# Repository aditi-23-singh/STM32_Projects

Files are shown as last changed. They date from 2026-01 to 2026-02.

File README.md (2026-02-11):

## Distributed Dual-Node Stepper Motor Control System
Bi-Directional UART Communication | Dual STM32 | TMC2208 | Event-Driven Firmware

## Project Summary

Designed and implemented a distributed embedded control architecture using two STM32F051 microcontrollers communicating over bi-directional UART, where both nodes are capable of controlling the same stepper motor through a TMC2208 driver.

The system supports:

    Motor control from either board
    Real-time command arbitration
    Single click → Start/Stop
    Double click → Reverse direction
    Long press → Mode control
    Deterministic timer-based pulse generation
    LED-assisted hardware debugging

This project demonstrates distributed embedded design, peripheral-level control, communication protocol handling, and real-time event synchronization.

## System Architecture
Both STM32 boards:
    
    Scan user inputs
    Generate control commands
    Transmit and receive via UART
    Update motor state based on synchronized command logic

Motor control authority is dynamically managed through command synchronization.

## Core Engineering Components
1. Bi-Directional UART Communication
    
    Full-duplex UART configuration
    Interrupt-driven RX handling
    Lightweight command protocol
    Conflict handling logic
    Command acknowledgment strategy

Key focus areas:

    Clock accuracy & baud rate matching
    Framing reliability
    Data integrity verification
    Real-time synchronization

This demonstrates understanding of multi-node embedded systems and communication integrity.

2️. Event-Based Input Engine

Implemented a structured FSM to detect:

    Single click
    Double click (timing window based)
    Long press
    Double click triggers direction reversal.

Key techniques:
    
    Edge detection
    Non-blocking timing logic
    Debounce filtering
    Deterministic state transitions

This reflects correct event-driven firmware design rather than delay-based logic.

3️. Deterministic Motor Control (TMC2208 – STEP/DIR Mode)

    Hardware timer-based pulse generation
    Adjustable step frequency
    Direction toggling without step loss
    Safe enable/disable sequencing
    Synchronization with UART events

Ensured:
    
    No missed steps during direction changes
    No blocking delays
    Pulse width constraints respected
    Stable motor operation under distributed command input

4️. Distributed Control Handling
    
    Since both boards can issue motor commands:
    Implemented command synchronization logic
    Prevented inconsistent motor states
    Ensured deterministic behavior under concurrent inputs

This models real-world distributed embedded systems where multiple controllers share authority.

5️. Structured Hardware Debugging

Used LED signaling as a deterministic debug interface:

    UART transmit/receive confirmation
    State machine transitions
    Direction change verification
    Error detection states

Also performed:

    Register-level inspection
    Timer debugging
    Peripheral clock validation
    Step signal probing

Demonstrates disciplined debugging methodology.

## Engineering Challenges Solved

    Reliable double-click detection under timing constraints
    UART synchronization between two MCUs
    Preventing step loss during direction reversal
    Avoiding race conditions in distributed control
    Maintaining deterministic pulse generation

## What This Project Demonstrates

This project reflects:

    Multi-controller embedded system design
    Real-time event-driven firmware
    Deterministic motor control
    Communication protocol implementation
    Structured debugging methodology
    Hardware-level reasoning under timing constraints
    It models a scaled-down version of distributed hardware control systems used in industrial and silicon enablement environments.
    Maintaining deterministic pulse generation

## Potential Extensions
    
    DMA-based UART communication
    Acceleration ramp (trapezoidal velocity profile)
    Arbitration protocol with priority logic
    RTOS-based task scheduling
    Closed-loop feedback with encoder
    CRC-based command validation

### Author

Aditi Singh
B.Tech – Electronics & Communication Engineering
NIT Sikkim

Focus Areas:

    Embedded Systems
    VLSI & Chip Design
    Hardware-Software Co-Design
    System Architecture

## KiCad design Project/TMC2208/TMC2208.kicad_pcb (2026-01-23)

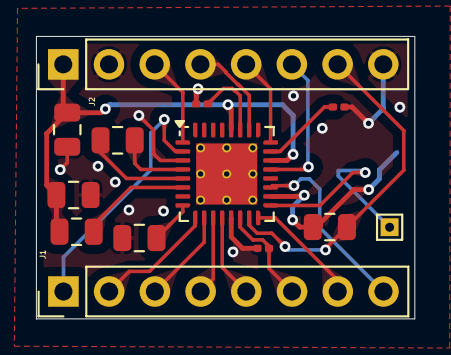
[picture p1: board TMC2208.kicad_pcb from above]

Board: 2 copper layers, 21.0 x 15.7 mm, 14 parts (1 on the bottom side), 22 nets.

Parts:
C1, C3, C6: 100nF; C_0805_2012Metric
C2: 22nF; C_0805_2012Metric
C4: 130uF; C_0805_2012Metric
C5: 4.7uF; C_0805_2012Metric
J1, J2: Conn_01x08_Pin; PinHeader_1x08_P2.54mm_Vertical
R1, R2: 0.11E; R_0201_0603Metric
R5: 10K; R_0201_0603Metric
R6: R_Variable; Potentiometer_Bourns_TC33X_Vertical
U2: TMC2208-LA; TQFN-32-1EP_5x5mm_P0.5mm_EP3.4x3.4mm_ThermalVias
Vref1: TestPoint_THTPad_1.0x1.0mm_Drill0.5mm

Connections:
/DIAG: J1.4, U2.11 (DIAG)
/DIR: J1.8, U2.19 (DIR)
/EN: J1.1, U2.2 (ENN)
/INDEX: J1.5, U2.12 (INDEX)
/M1A: J2.5, U2.24 (OA1)
/M1B: J2.4, U2.26 (OB1)
/M2A: J2.6, U2.21 (OA2)
/M2B: J2.3, U2.1 (OB2)
/MS1: J1.2, U2.9 (MS1)
/MS2: J1.3, U2.10 (MS2)
/PDN_UART: J1.6, R5.2, U2.14 (PDN_UART)
/STEP: J1.7, U2.16 (STEP)
/VIO: C3.2, J2.7, U2.15 (VCC_IO)
/VM: C1.1, C4.1, C6.1, J2.1, U2.22 (VS), U2.28 (VS)
GND: C3.1, C4.2, C5.2, C6.2, J2.2, J2.8, R1.2, R2.2, R5.1, R6.1, U2.3 (GND), U2.13 (CLK), U2.18 (GND)
unnamed: C5.1, U2.8 (5VOUT)
unnamed: R2.1, U2.23 (BRA)
unnamed: R1.1, U2.27 (BRB)
unnamed: C2.1, U2.5 (CPI)
unnamed: C2.2, U2.4 (CPO)
unnamed: C1.2, U2.6 (VCP)
unnamed: R6.2, U2.17 (VREF), Vref1.1

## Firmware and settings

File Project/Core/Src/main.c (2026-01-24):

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
/* Includes ------------------------------------------------------------------*/
#include "main.h"
#include "usart.h"
#include "gpio.h"

/* USER CODE BEGIN Includes */
#include "Application.h"
#include "UART_Application.h"
#include "ButtonCore.h"
#include "LED_Controller.h"
#include <stdio.h>
#include "TMC2208_Registers.h"
#include "TMC2208_Driver.h"

/* USER CODE END Includes */


/* USER CODE BEGIN PV */
Button_t userButton;

TMC2208_t motor1;

/* USER CODE END PV */

void SystemClock_Config(void);
/**
  * @brief  The application entry point.
  * @retval int
  */
int main(void)
{

  /* MCU Configuration--------------------------------------------------------*/

  /* Reset of all peripherals, Initializes the Flash interface and the Systick. */
  HAL_Init();

  /* Configure the system clock */
  SystemClock_Config();

  /* USER CODE BEGIN SysInit */
  MX_USART1_UART_Init();
  MX_USART2_UART_Init();
  ApplicationInit();
  ButtonCore_Init(&userButton, Button_GPIO_Port, Button_Pin);


  /* USER CODE END SysInit */

  /* Initialize all configured peripherals */
  MX_GPIO_Init();
  MX_USART1_UART_Init();
  MX_USART2_UART_Init();
  /* Infinite loop */
  /* USER CODE BEGIN WHILE */


 while (1)
 {

//
	  ApplicationProcess();
	  ButtonCore_Update(&userButton);
	  LCDApplication_Process();

    /* USER CODE END WHILE */

    /* USER CODE BEGIN 3 */


  }
  /* USER CODE END 3 */
}

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
/* USER CODE BEGIN 4 */

void HAL_SYSTICK_Callback(void)
{

    HandleTick();
}

void HAL_UART_RxCpltCallback(UART_HandleTypeDef *huart)
{


    if(huart->Instance == USART1)
    {
        UART_OnByteReceived();
    }

}
/* USER CODE END 4 */
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


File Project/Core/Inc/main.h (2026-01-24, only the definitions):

#define ROW1_Pin GPIO_PIN_0
#define ROW1_GPIO_Port GPIOC
#define ROW2_Pin GPIO_PIN_1
#define ROW2_GPIO_Port GPIOC
#define ROW3_Pin GPIO_PIN_2
#define ROW3_GPIO_Port GPIOC
#define ROW4_Pin GPIO_PIN_3
#define ROW4_GPIO_Port GPIOC
#define Button_Pin GPIO_PIN_0
#define Button_GPIO_Port GPIOA
#define COL1_Pin GPIO_PIN_4
#define COL1_GPIO_Port GPIOC
#define COL2_Pin GPIO_PIN_5
#define COL2_GPIO_Port GPIOC
#define RS_Pin GPIO_PIN_0
#define RS_GPIO_Port GPIOB
#define E_Pin GPIO_PIN_1
#define E_GPIO_Port GPIOB
#define D4_Pin GPIO_PIN_2
#define D4_GPIO_Port GPIOB
#define COL3_Pin GPIO_PIN_6
#define COL3_GPIO_Port GPIOC
#define COL4_Pin GPIO_PIN_7
#define COL4_GPIO_Port GPIOC
#define LD4_Pin GPIO_PIN_8
#define LD4_GPIO_Port GPIOC
#define LD3_Pin GPIO_PIN_9
#define LD3_GPIO_Port GPIOC
#define SWDIO_Pin GPIO_PIN_13
#define SWDIO_GPIO_Port GPIOA
#define SWCLK_Pin GPIO_PIN_14
#define SWCLK_GPIO_Port GPIOA
#define ROW5_Pin GPIO_PIN_10
#define ROW5_GPIO_Port GPIOC
#define D5_Pin GPIO_PIN_3
#define D5_GPIO_Port GPIOB
#define D6_Pin GPIO_PIN_4
#define D6_GPIO_Port GPIOB
#define D7_Pin GPIO_PIN_5
#define D7_GPIO_Port GPIOB
#define STEP_Pin GPIO_PIN_6
#define STEP_GPIO_Port GPIOB
#define DIR_Pin GPIO_PIN_7
#define DIR_GPIO_Port GPIOB
#define EN_Pin GPIO_PIN_8
#define EN_GPIO_Port GPIOB

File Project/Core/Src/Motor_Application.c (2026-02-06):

#include "Motor_Application.h"
#include "Motor_Controller.h"
#include "gpio.h"
#include <stdio.h>
#include "string.h"

extern MotorController_t MotorControl;

#define STEPS_PER_MOVE 200
#define PERIOD_MEDIUM_US 2000
#define PERIOD_SLOW_US 5000
#define PERIOD_FAST_US 1000

void MotorApplication_Init(void) {

	Motor_Init();
}

void MotorApplication_SetMotorMode(EVENT_CODES_ENUM event) {
    switch (event) {
        case EVT_SINGLE_CLICK:
        	MotorControl.direction = -1;
        	MotorControl.period_us = PERIOD_MEDIUM_US;
        	MotorControl.steps_remaining = STEPS_PER_MOVE;
        	MotorControl.running = 1;
            break;

        case EVT_DOUBLE_CLICK:
        	MotorControl.direction = 1;
        	MotorControl.period_us = PERIOD_SLOW_US;
        	MotorControl.steps_remaining = STEPS_PER_MOVE;
        	MotorControl.running = 1;
            break;

        case EVT_HOLD_START:
        	MotorControl.direction = -1;
        	MotorControl.period_us = PERIOD_MEDIUM_US;
        	MotorControl.steps_remaining = 0;
        	MotorControl.running = 1;
            break;

        case EVT_FACET_CW:
                   MotorControl.direction = 1;
                   MotorControl.period_us = PERIOD_FAST_US;
                   MotorControl.steps_remaining = 0;
                   MotorControl.running = 1;
                   break;

        case EVT_FACET_CCW:
                   MotorControl.direction = -1;
                   MotorControl.period_us = PERIOD_FAST_US;
                   MotorControl.steps_remaining = 0;
                   MotorControl.running = 1;
                   break;
        case EVT_GRAIN_CW:
                  MotorControl.direction = 1;
                  MotorControl.period_us = PERIOD_FAST_US;
                  MotorControl.steps_remaining = 0;
                  MotorControl.running = 1;
                  break;

         case EVT_GRAIN_CCW:
                  MotorControl.direction = -1;
                  MotorControl.period_us = PERIOD_FAST_US;
                  MotorControl.steps_remaining = 0;
                  MotorControl.running = 1;
                  break;

        case EVT_HOLD_END:
        	MotorControl.running = 0;
        	MotorControl.accumulator_us = 0;
            break;

    }

}

void MotorApplication_Update(void) {

	Motor_Update();
}

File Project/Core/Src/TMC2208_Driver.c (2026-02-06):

#include "TMC2208_Driver.h"
#include <string.h>

#define TMC_SYNC_BYTE  0x05
#define TMC_READ_REQ_LEN 4
#define TMC_WRITE_REQ_LEN 8
#define TMC_REPLY_LEN 12

uint8_t debug_tx_status = 0;
uint8_t debug_rx_status = 0;
uint8_t debug_reply_sync = 0;
uint8_t debug_reply_addr = 0;
uint8_t debug_reply_reg = 0;
uint8_t debug_calc_crc = 0;
uint8_t debug_recv_crc = 0;
uint32_t debug_raw_value = 0;
bool debug_crc_match = false;
uint8_t debug_uart_state = 0;

uint8_t CRC1 = 0;
uint8_t RxDummy[12] = {0};
uint8_t TxBuffer[8];

static uint8_t CalcCRC(uint8_t *datagram, uint8_t len) {
    uint8_t crc = 0;
    for (int i = 0; i < len; i++) {
        uint8_t currentByte = datagram[i];
        for (int j = 0; j < 8; j++) {
            if ((crc >> 7) ^ (currentByte & 0x01)) {
                crc = (crc << 1) ^ 0x07;
            } else {
                crc = (crc << 1);
            }
            currentByte = currentByte >> 1;
        }
    }
    return crc;
}

void UART_FlushRx(UART_HandleTypeDef *huart)
{
    volatile uint32_t tmp;
    while (__HAL_UART_GET_FLAG(huart, UART_FLAG_RXNE))
    {
        tmp = huart->Instance->RDR;
        (void)tmp;
    }
}

void TMC_Init(TMC2208_t *driver, UART_HandleTypeDef *uart_handle, uint8_t slave_addr) {
    driver->uartHandle = uart_handle;
    driver->slaveAddress = slave_addr;
    driver->isCRCError = false;
    driver->shadow_gconf = 0;
    driver->shadow_ihold_irun = 0;
    driver->shadow_ioin = 0;
}

void TMC_WriteRegister(TMC2208_t *driver, uint8_t reg_addr, uint32_t data) {
    TxBuffer[0] = TMC_SYNC_BYTE;
    TxBuffer[1] = driver->slaveAddress;
    TxBuffer[2] = reg_addr | 0x80;
    TxBuffer[3] = (data >> 24) & 0xFF;
    TxBuffer[4] = (data >> 16) & 0xFF;
    TxBuffer[5] = (data >> 8) & 0xFF;
    TxBuffer[6] = data & 0xFF;
    TxBuffer[7] = CalcCRC(TxBuffer, 7);

    UART_FlushRx(driver->uartHandle);

    debug_tx_status = HAL_UART_Transmit(driver->uartHandle, TxBuffer, 8, 100);

    uint8_t dummy[8];
    debug_rx_status = HAL_UART_Receive(driver->uartHandle, dummy, 8, 50);
}

bool TMC2208_SyncUART(TMC2208_t *driver)
{
    if (driver == NULL || driver->uartHandle == NULL)
        return false;

    uint32_t dummy;

    UART_FlushRx(driver->uartHandle);
    HAL_Delay(10);

    TMC_ReadRegister(driver, TMC2208_GCONF, &dummy);
    HAL_Delay(10);

    UART_FlushRx(driver->uartHandle);

    return true;
}

bool TMC_ReadRegister(TMC2208_t *driver, uint8_t reg_addr, uint32_t *value) {
    if (driver == NULL || value == NULL) {
        return false;
    }

    uint8_t txBuffer[4];
    uint8_t RxBuffer[12] = {0};


    txBuffer[0] = TMC_SYNC_BYTE;
    txBuffer[1] = driver->slaveAddress;
    txBuffer[2] = reg_addr;
    txBuffer[3] = CalcCRC(txBuffer, 3);

    UART_FlushRx(driver->uartHandle);
    __HAL_UART_FLUSH_DRREGISTER(driver->uartHandle);


    debug_uart_state = driver->uartHandle->gState;

    HAL_StatusTypeDef tx_stat = HAL_UART_Transmit(driver->uartHandle, txBuffer, 4, 100);
    debug_tx_status = tx_stat;

    if (tx_stat != HAL_OK) {
        return false;
    }

    HAL_Delay(2);

    HAL_StatusTypeDef rx_stat = HAL_UART_Receive(driver->uartHandle, RxBuffer, 12, 100);
    debug_rx_status = rx_stat;

    if (rx_stat != HAL_OK) {
        return false;
    }


    for (int i = 0; i < 12; i++) {
        RxDummy[i] = RxBuffer[i];
    }

    uint8_t *reply = &RxBuffer[4];


    debug_reply_sync = reply[0];
    debug_reply_addr = reply[1];
    debug_reply_reg = reply[2];


    if (reply[0] != TMC_SYNC_BYTE) {
        return false;
    }


    if (reply[1] != 0xFF) {
        return false;
    }


    if (reply[2] != reg_addr) {
        return false;
    }


    debug_raw_value = ((uint32_t)reply[3] << 24) |
                      ((uint32_t)reply[4] << 16) |
                      ((uint32_t)reply[5] << 8)  |
                      ((uint32_t)reply[6]);


    debug_calc_crc = CalcCRC(reply, 7);
    debug_recv_crc = reply[7];
    debug_crc_match = (debug_calc_crc == debug_recv_crc);

    if (!debug_crc_match) {
        driver->isCRCError = true;
        return false;
    }

    driver->isCRCError = false;
    *value = debug_raw_value;

    return true;
}

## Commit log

2025-12-22 Initial commit: STM32F0 LED delay control with single/double click
2025-12-22 Initial commit: STM32_Projects
2025-12-24 Revert "Changes made in hold1 regarding over-writing"
    This reverts commit c38fc64fdb5875b58a89748a36d90eb9b5eff059.
    [main.c]
2025-12-25 Ignore Drivers ,Debug directories and metdata
2025-12-26 UART PEER TO PEER COMMUNICATION- WIP
2025-12-26 Further work on UART
2025-12-27 CORRECTED LAG BETWEEN TX AND RX
    [LCD.c, LEDApplication.c, UART_Application.c]
2025-12-29 RESET THE TIMER BETWEEN EVENT
    [LEDApplication.c, main.c]
2025-12-29 Refactored LEDApplications
2025-12-29 REFACTORED ButtonHandler- WIP
2025-12-29 ButtonHandler refactored-final
2025-12-30 Refactored LCDApplications and UART
2025-12-30 Parameterized LED blink timings
2025-12-31 Implement 4-line LCD layout for local/remote mode and LED status
2025-12-31 FIXED DELAY BETWEEN CALLS
    [LCDApplication.h]
2026-01-02 TMC2208 UART WITH STM32F0 -WIP
2026-01-05 Full Duplex UART TMC2208
2026-01-23 Ki-CAD: TMC2208-WIP2
    [TMC2208.kicad_pcb, TMC2208.kicad_sch]
2026-01-25 Integrated Motor Driver TMC2208 in Standalone Mode

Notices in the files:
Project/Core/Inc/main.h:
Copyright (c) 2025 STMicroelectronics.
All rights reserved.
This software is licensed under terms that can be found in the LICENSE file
